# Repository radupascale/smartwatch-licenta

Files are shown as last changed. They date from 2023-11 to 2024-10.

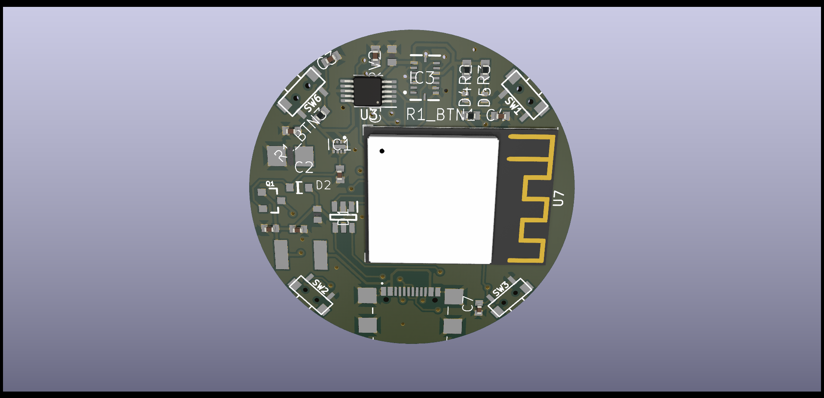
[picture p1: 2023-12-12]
board/proto/docs/route_v1/3d_front.png

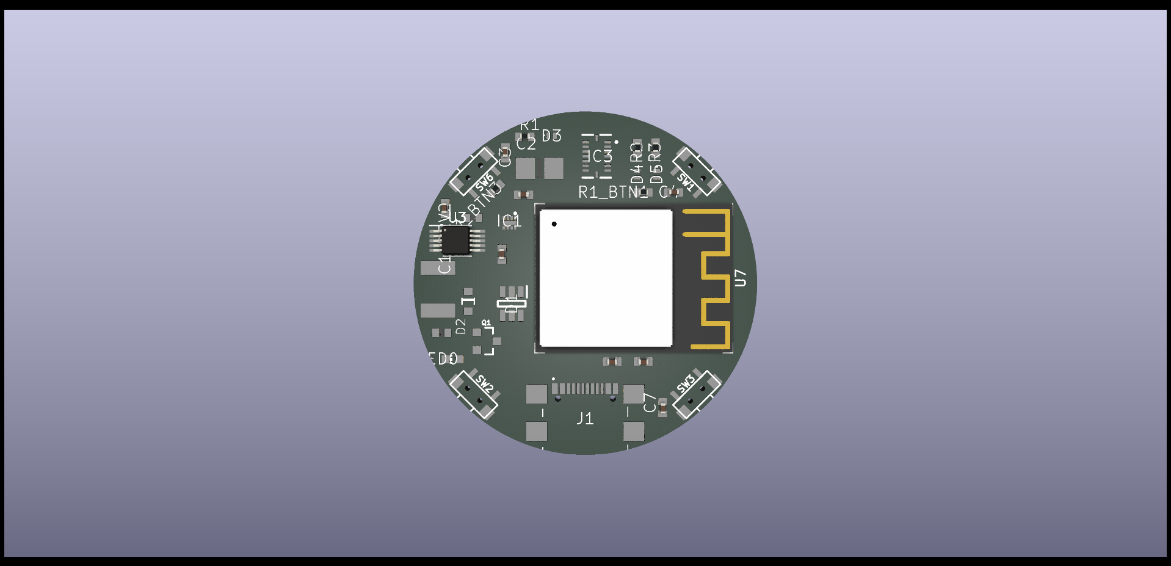
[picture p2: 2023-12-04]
board/proto/docs/proto_v1/3d_front.png

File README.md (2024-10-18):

# Intro

<p align="center">

</p>

This repository contains all the files necessary to build the smartwatch I developed for my thesis at the Computer Science Faculty of UPB.
I plan to add step-by-step building instructions in the future, but for now I'll leave only an overview of the directory structure.

- board: Schematics and PCB layout
    - fusion: Fusion project archive
    - proto: KiCad prototype project
- CAD
    - 3d-files: .stl files for 3D printing the case
    - components: .STEP files for some components
- src: platform.io project files and deps

# Building

```bash
git clone --recurse-submodules git@github.com:radupascale/smartwatch-licenta.git
```

Afterwards open the `src` directory and build&upload using `platformio` (this project used the VScode extension).

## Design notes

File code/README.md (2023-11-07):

## Referinte
- [Hookup display esp32](https://dronebotworkshop.com/gc9a01/)
- [Test display code](https://community.platformio.org/t/tft-display-works-in-arduino-ide-doesnt-in-platformio/33269/5)

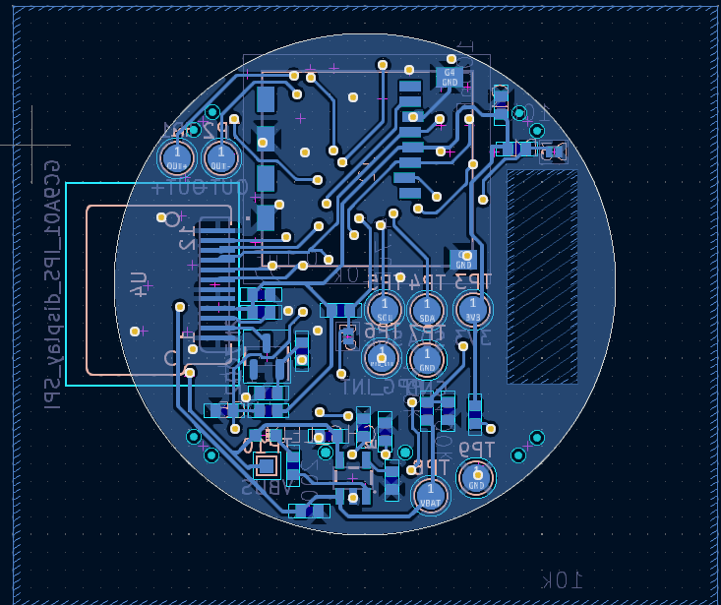
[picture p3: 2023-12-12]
board/proto/docs/route_v1/back.png

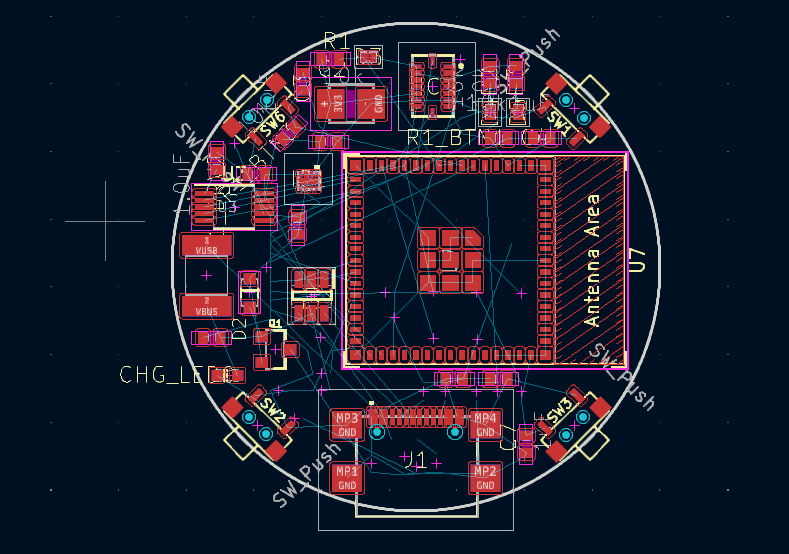
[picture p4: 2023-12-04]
board/proto/docs/proto_v1/front_pcb.png

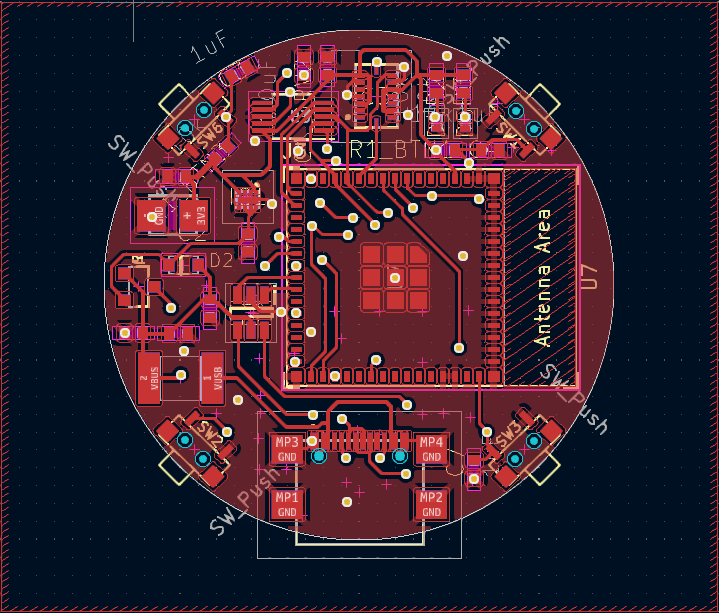
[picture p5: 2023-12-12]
board/proto/docs/route_v1/front.png

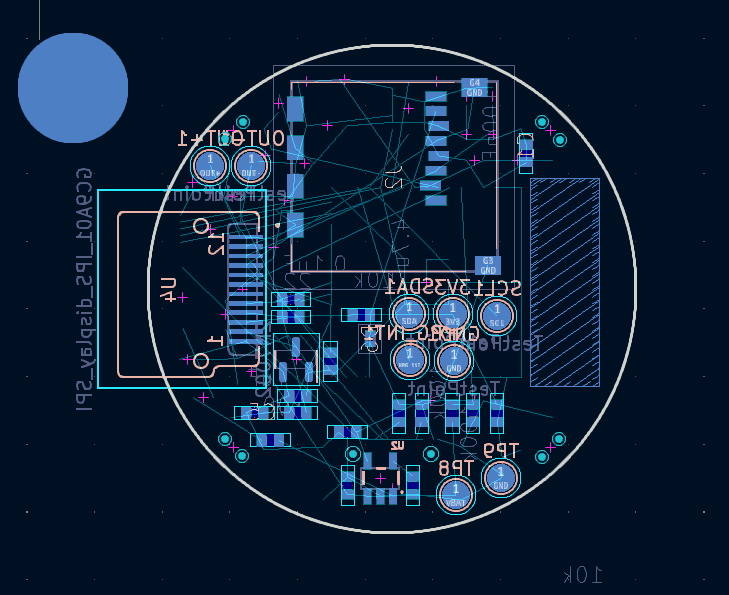
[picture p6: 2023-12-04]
board/proto/docs/proto_v1/back_pcb.png

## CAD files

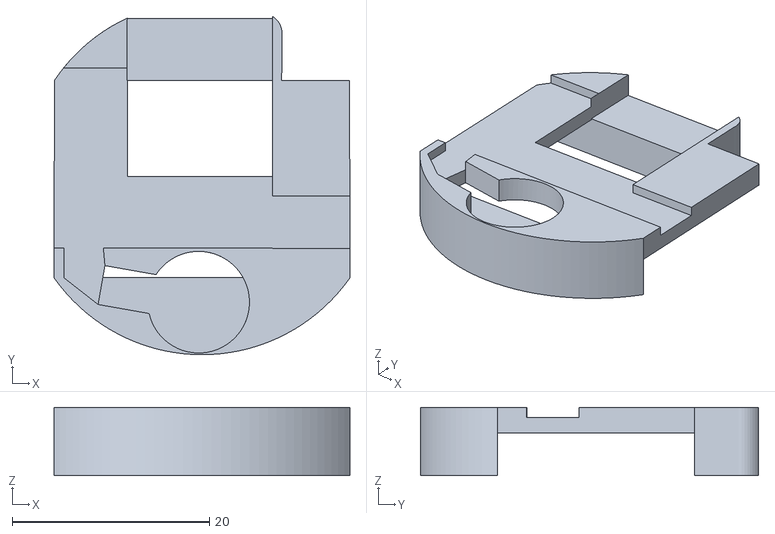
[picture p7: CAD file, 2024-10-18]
CAD/3d-files/battery_holder.stl
30.0 x 34.3 x 6.90

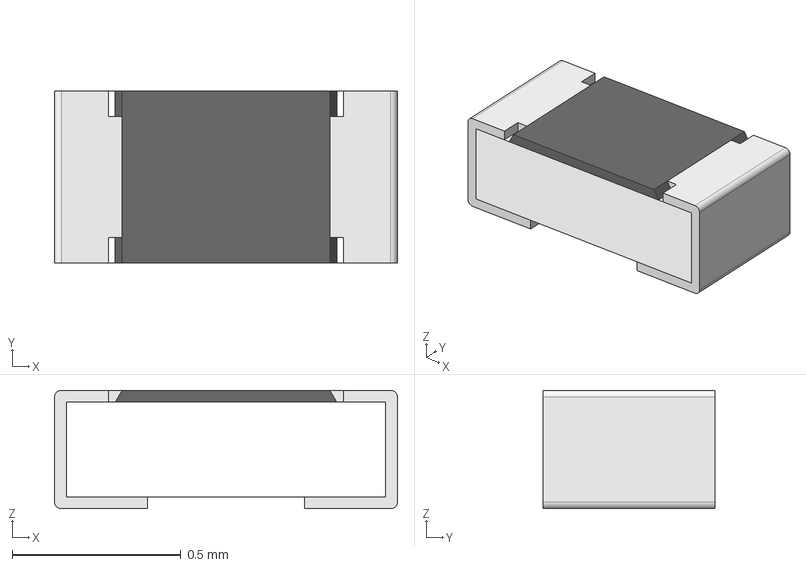
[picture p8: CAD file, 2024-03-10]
CAD/components/Resistor_0402.step
1.02 x 0.508 x 0.35 mm
Pin1
Pin2
CeramicBody
Coating

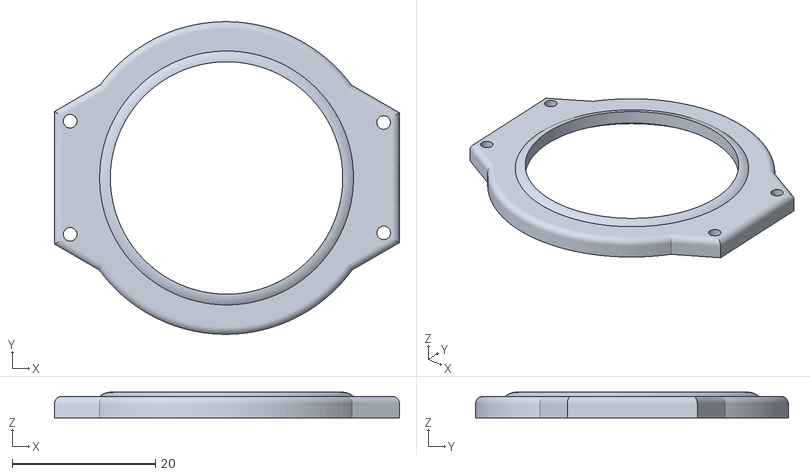
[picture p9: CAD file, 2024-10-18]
CAD/3d-files/top_layer.stl
48.1 x 43.6 x 3.60

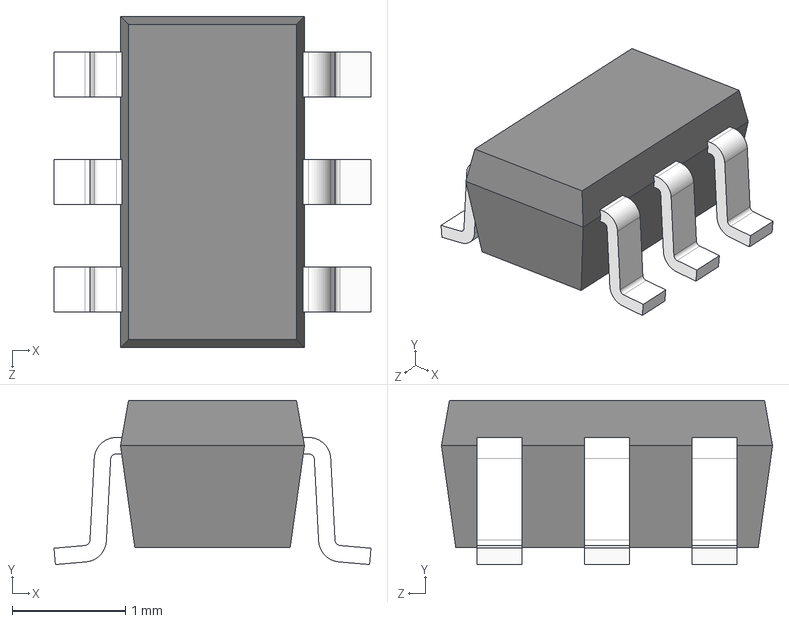
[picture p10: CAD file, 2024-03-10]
CAD/components/USBLC6-2SC6Y--3DModel-STEP-56544.STEP
2.80 x 1.45 x 2.92 mm

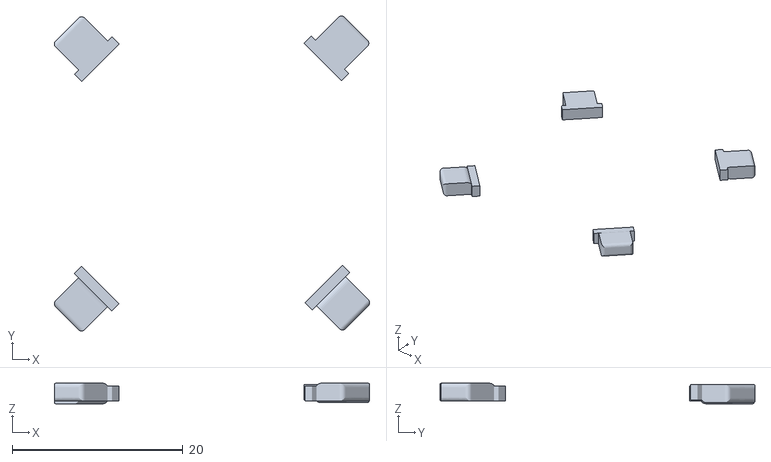
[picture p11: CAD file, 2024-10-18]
CAD/3d-files/buttons.stl
36.9 x 36.8 x 2.40

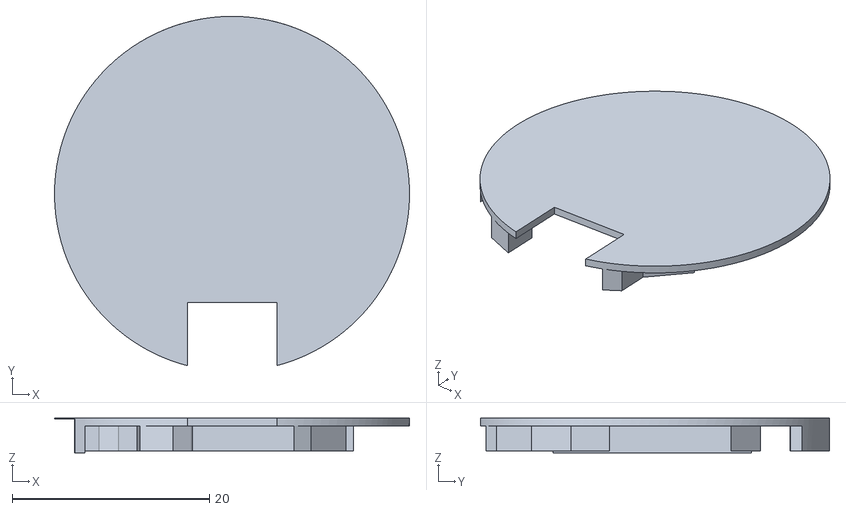
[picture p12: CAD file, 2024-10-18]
CAD/3d-files/interposer.stl
36.0 x 35.4 x 3.50

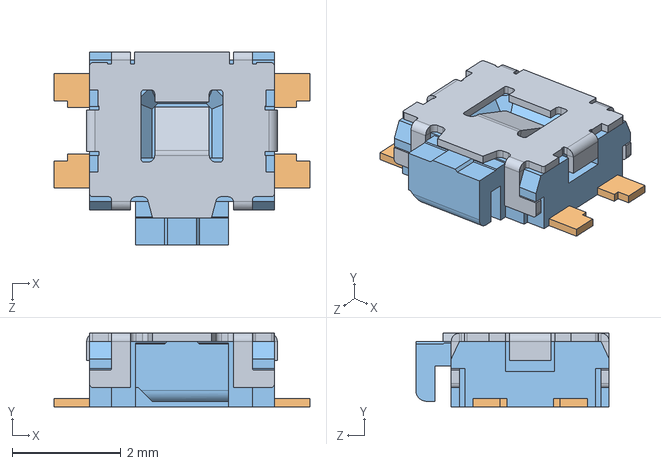
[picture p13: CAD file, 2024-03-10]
CAD/components/EVQ-P7A01P--3DModel-STEP-269445.STEP
4.70 x 1.35 x 3.55 mm

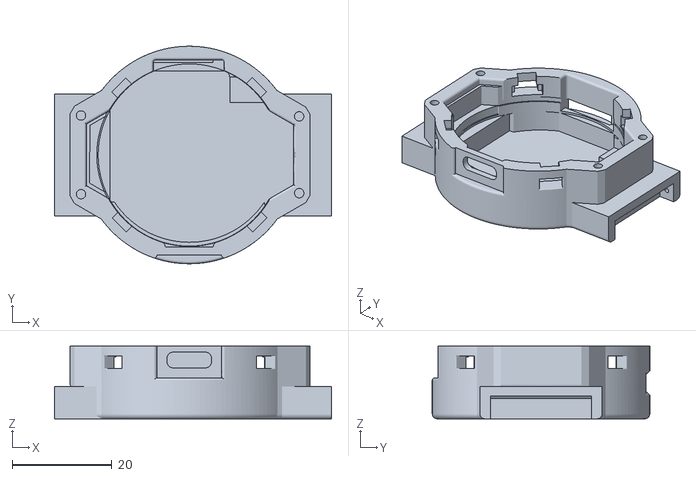
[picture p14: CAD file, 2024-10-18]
CAD/3d-files/bottom_layer.stl
55.5 x 43.6 x 14.5

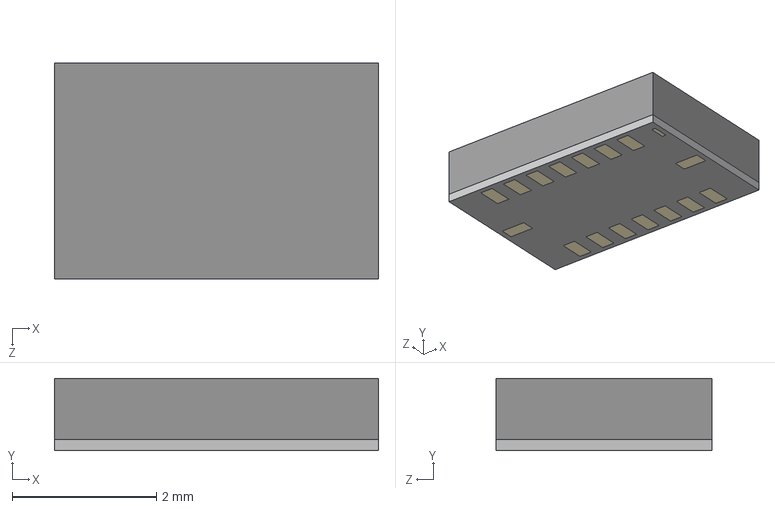
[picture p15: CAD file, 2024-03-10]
CAD/components/BMI085--3DModel-STEP-56544.STEP
4.50 x 1.00 x 3.00 mm

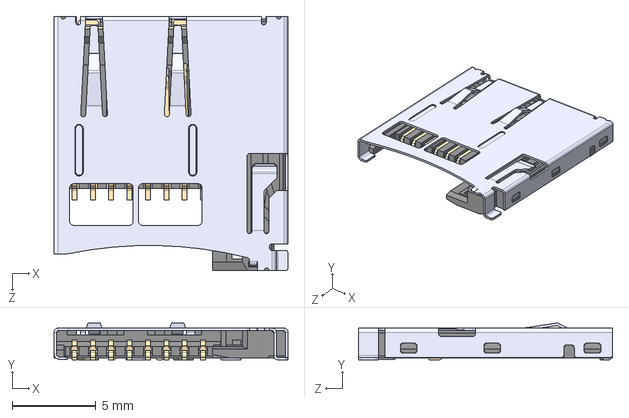
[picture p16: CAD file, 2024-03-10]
CAD/components/112A-TAAR-R03--3DModel-STEP-56544.STEP
14.0 x 2.20 x 15.2 mm

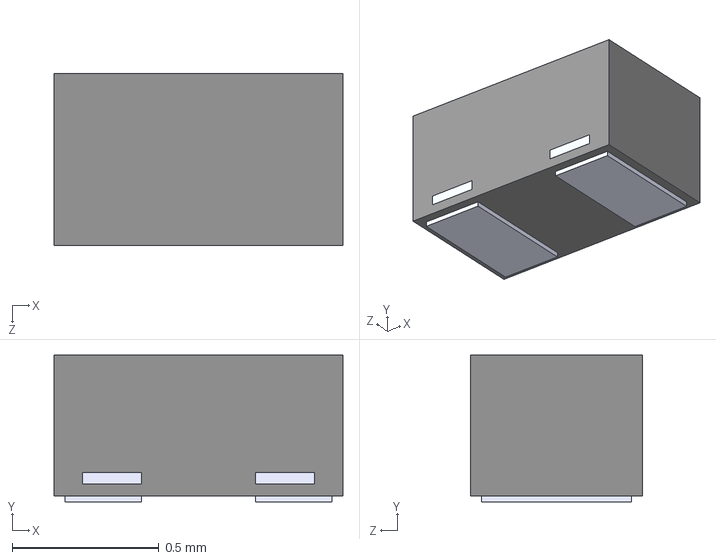
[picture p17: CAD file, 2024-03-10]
CAD/components/PESD5V0S1BL,315.STEP
0.985 x 0.5 x 0.585 mm

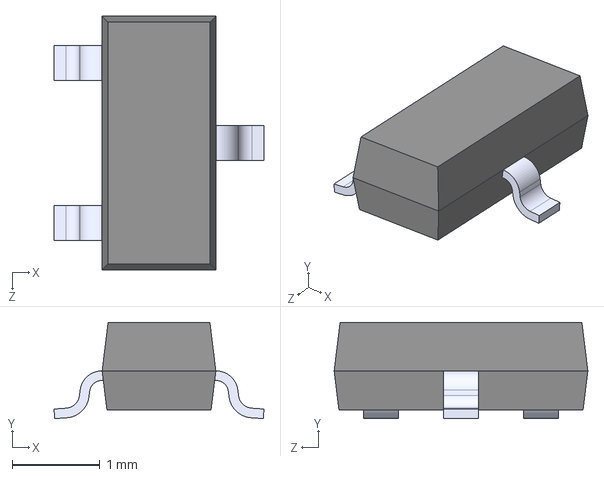
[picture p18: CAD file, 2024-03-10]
CAD/components/DMG2305UX-7.STEP
2.40 x 1.10 x 2.90 mm

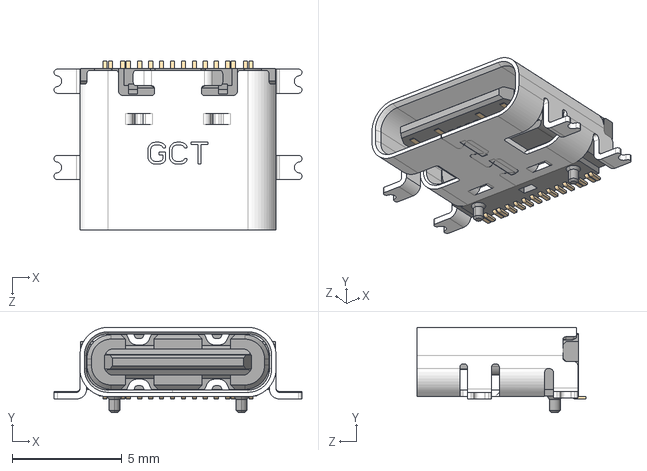
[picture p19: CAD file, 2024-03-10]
CAD/components/USB4110GFA--3DModel-STEP-269445.STEP
11.3 x 3.89 x 7.70 mm

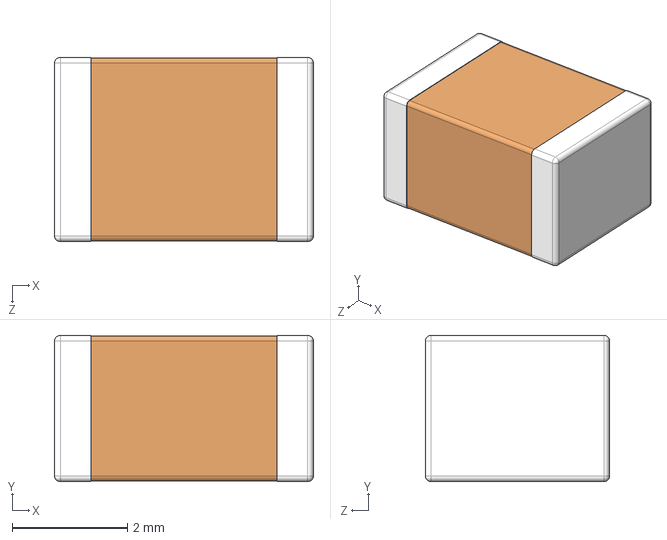
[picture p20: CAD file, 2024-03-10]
CAD/components/VC181238U770DP.STEP
4.50 x 2.54 x 3.20 mm

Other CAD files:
CAD/components/MCP73831T-2ACI_OT.STEP

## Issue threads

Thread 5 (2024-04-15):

Use LVGL with Adafruit GFX

radupascale, 2024-04-15:
The plan is to use Arduino GFX as the backend and LVGL as the frontend because in with it you can preview your work [1] without having to actually upload it to the board.

- [x] update&display test loop

Also, for synchronizing between different tasks which use the LVGL API, use this as a reference [2].

[1] [Simulator](https://docs.lvgl.io/8.1/get-started/pc-simulator.html)
[2] [How to integrate with FreeRTOS](https://github.com/lvgl/lvgl/issues/347#issuecomment-410502996)

Closed 2024-04-23.

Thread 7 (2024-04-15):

3D Case working prototype

radupascale, 2024-04-15:
Redo the 3D case in order to have something in which you can carry the PCB with all other peripherals. Don't over engineer the buttons, just make them click and move.

radupascale, 2024-04-26:
Some more adjustments:

- the buttons should have a hole carved inside of the PCB because right now it's difficult to assemble the case. I should also make them T shaped.
- snap fit between the mid and the bottom layer
- the PCB shouldn't move once you slide it in
- the display should stay level and not lift the PCB with it because this causes some buttons to me misaligned (although this should be fixed with the next PCB iteration). One quick fix would be to lift the button holes 0.1mm
- Top part should snap fit on the display as well as on the mid layer so that it keeps everything into place
- finesse USB port

radupascale, 2024-04-29:
commit a848d6ad20e196f3375dfab03bc0c9b65c634bd9 adds .step files for 3d printing

Closed 2024-04-29.

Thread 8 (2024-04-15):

Test each module

radupascale, 2024-04-15:
I only have these 2 things to test and I'm pretty confident that they will work. However, I need to first make the 3D case #[1].

- [x] PPG
- [x] Haptic motors

[1] https://github.com/radupascale/licenta/issues/7

Closed 2024-04-19.

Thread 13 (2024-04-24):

software core

radupascale, 2024-04-24:
- [x] [main watchface](https://github.com/radupascale/smartwatch-licenta/issues/12)
   - [x] real time
   - [x] app navigation (with another dummy app)
- [x] button event handling
- [x] reading sensor data
  - [x] battery level
  - [x] pedometer #17
- [x] persistent data
  - [x] steps in flash
  - [x] clock time in flash (in case wifi doesn't work)
 - [x] wifi connect option #16

radupascale, 2024-06-24:
8e7f657

Closed 2024-06-24.

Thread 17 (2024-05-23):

Pedometer implementation

radupascale, 2024-05-23:
- [x] pedometer class for reading and interpreting sensor data
- [x] test step count
- [x] step count logging on board and kept across reboots

radupascale, 2024-06-03:
It kind of works (although there are lots of false positives if you move your hand very fast). I'm closing this issue and opening another with for optimizing the algorithm (when I'll have more time).

Closed 2024-06-03.

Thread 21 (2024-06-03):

Repair DRV and motor

radupascale, 2024-06-03:

radupascale, 2024-06-05:
EN pin was not set when sending I2C commands. Apparently setting it to LOW makes the module go in a _low power state_ [1] in which it responds to I2C messages, but writing to registers is undefined behaviour.

[1] https://www.ti.com/lit/ds/symlink/drv2605.pdf

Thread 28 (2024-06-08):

Find battery discharge curve using the internal ADC

radupascale, 2024-06-08:

radupascale, 2024-06-11:
This b102c31 and the previous commit replace the lookup function and provide a script for computing it using adc data

Closed 2024-06-11.

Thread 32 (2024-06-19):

Poll sensors using ULP

radupascale, 2024-06-19:
Read about this [1], maybe it's useful for polling the IMU while the microcontroller is in sleep mode.

[1] https://docs.espressif.com/projects/esp-idf/en/stable/esp32/api-reference/system/ulp.html

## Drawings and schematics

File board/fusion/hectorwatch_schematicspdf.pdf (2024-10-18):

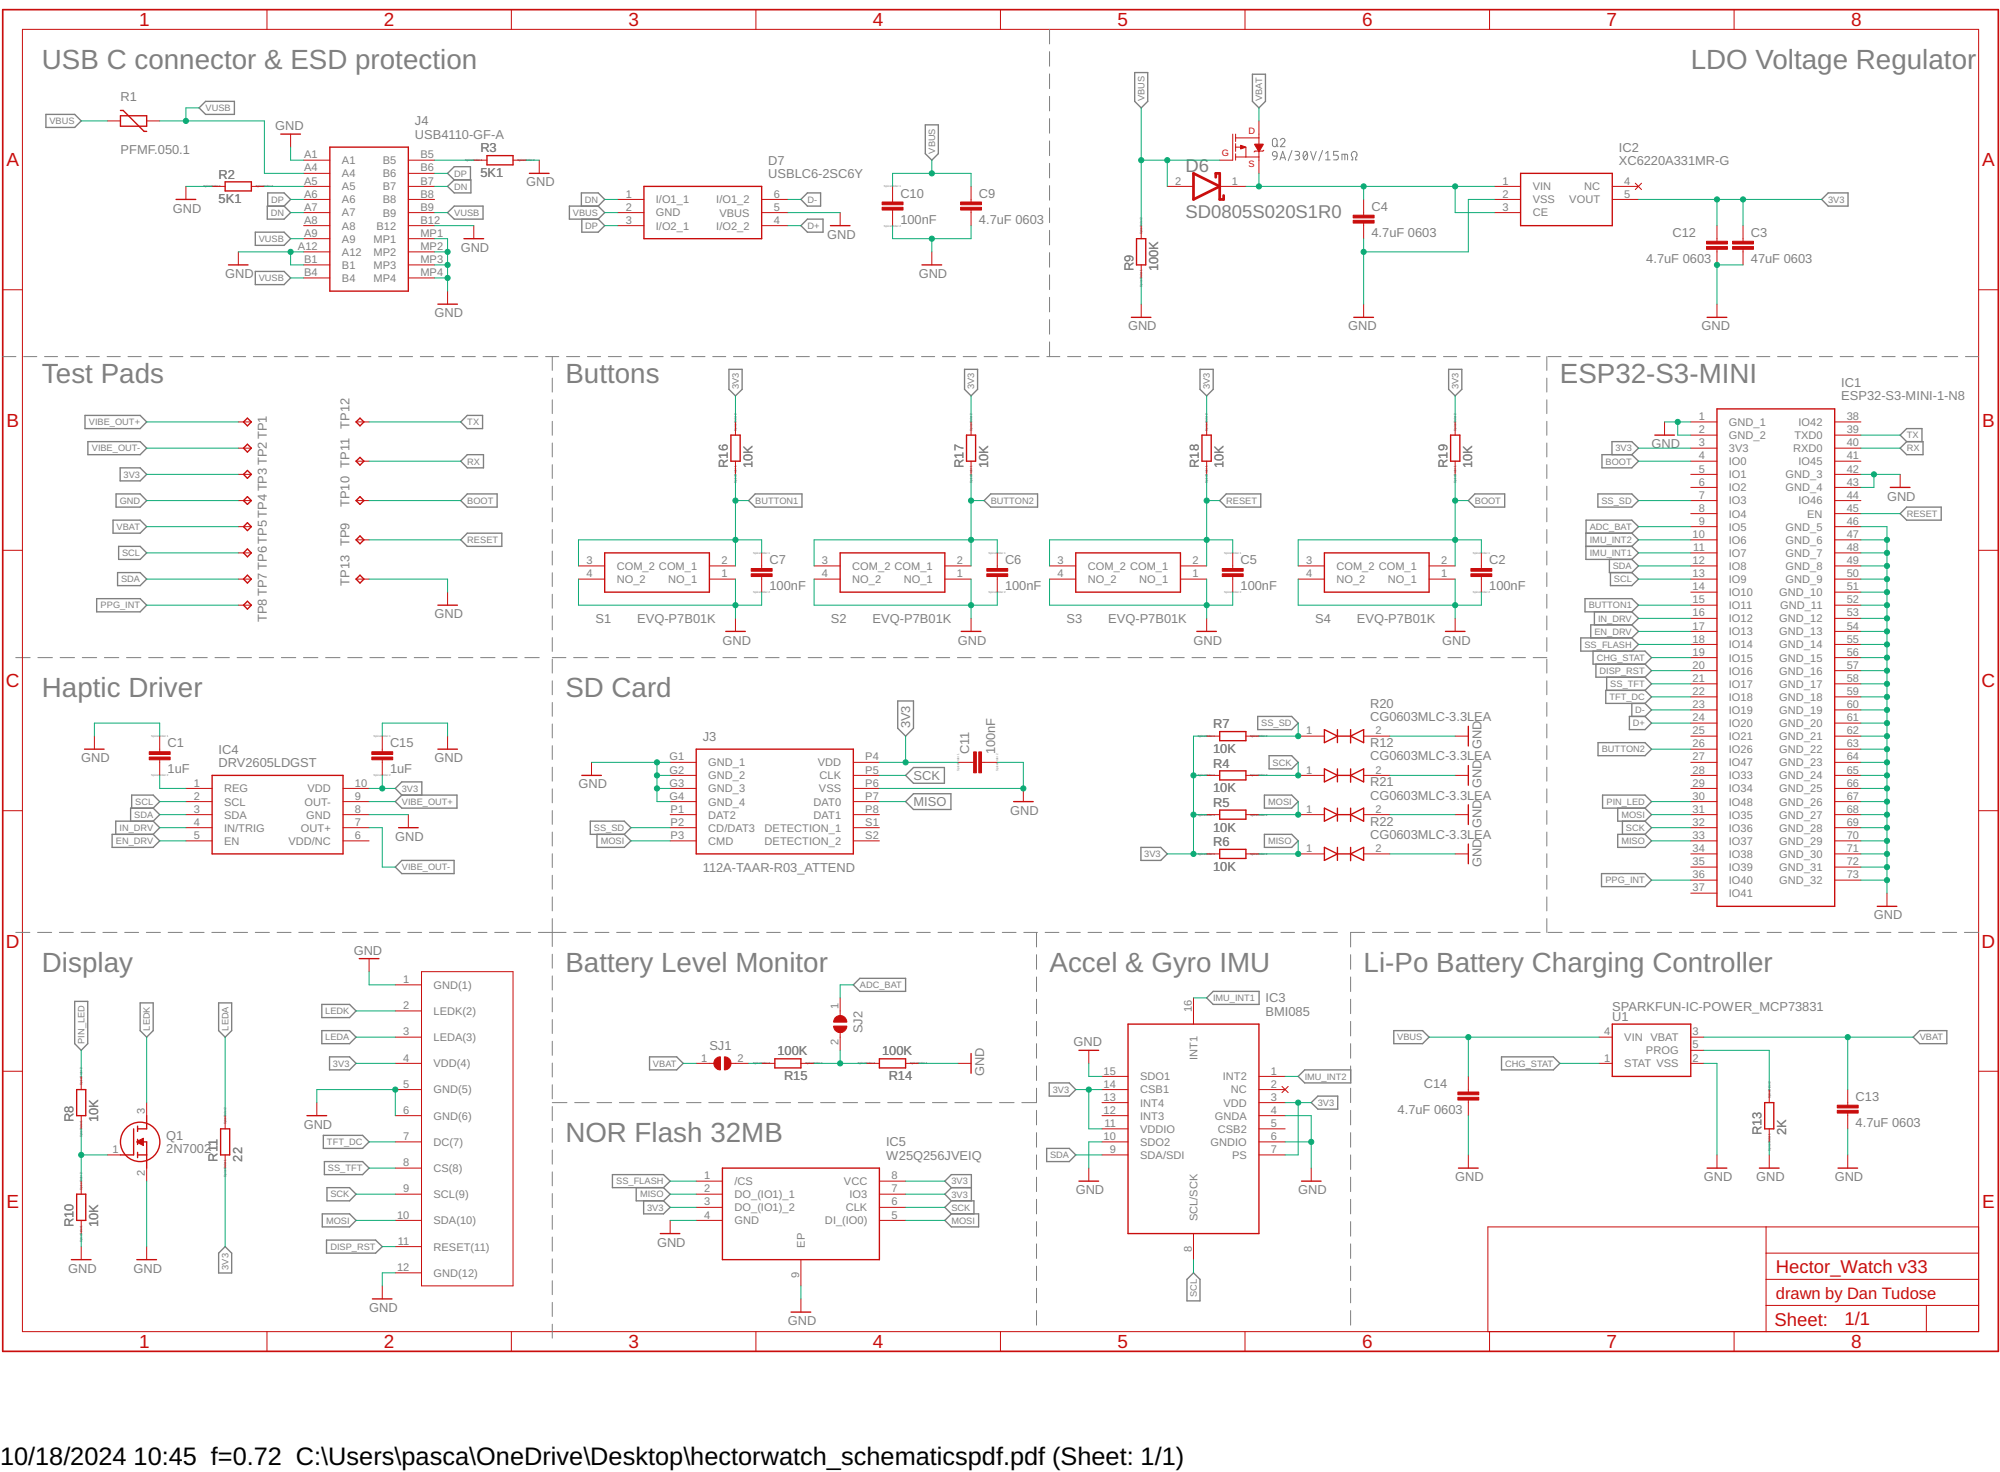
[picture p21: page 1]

USB C connector & ESD protection

SpiceOrder 1 SpiceOrder 2

GND GND

SpiceOrder 1 SpiceOrder 2 SpiceOrder 1 SpiceOrder 2 SpiceOrder 1

10 IMU_INT2 | 47 GND_7

SpiceOrder 1 SpiceOrder 2 SpiceOrder 1 SpiceOrder 2

5 GNDA 4 GNDIO 6

3V3 4 | SCK

drawn by Dan Tudose Hector_Watch v33

10/18/2024 10:45 f=0.72 C:\Users\pasca\OneDrive\Desktop\hectorwatch_schematicspdf.pdf (Sheet: 1/1)

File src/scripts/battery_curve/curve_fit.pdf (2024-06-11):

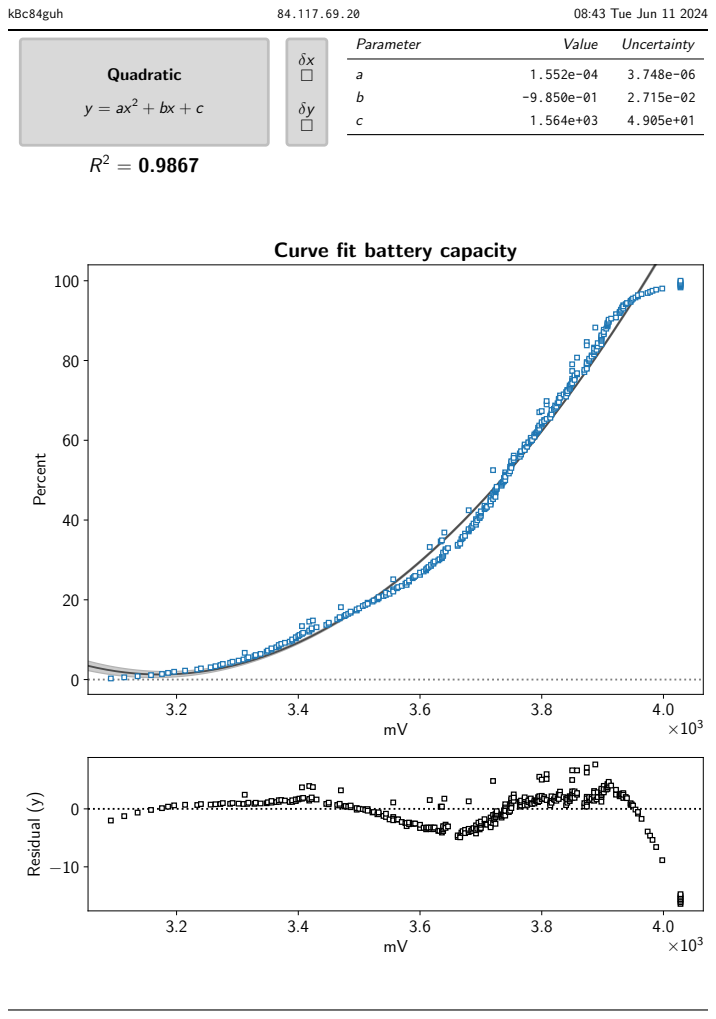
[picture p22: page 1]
kBc84guh; 08:43 Tue Jun 11 2024; Quadratic; Parameter; Value; Uncertainty; Percent; Residual (y)

Curve fit battery capacity

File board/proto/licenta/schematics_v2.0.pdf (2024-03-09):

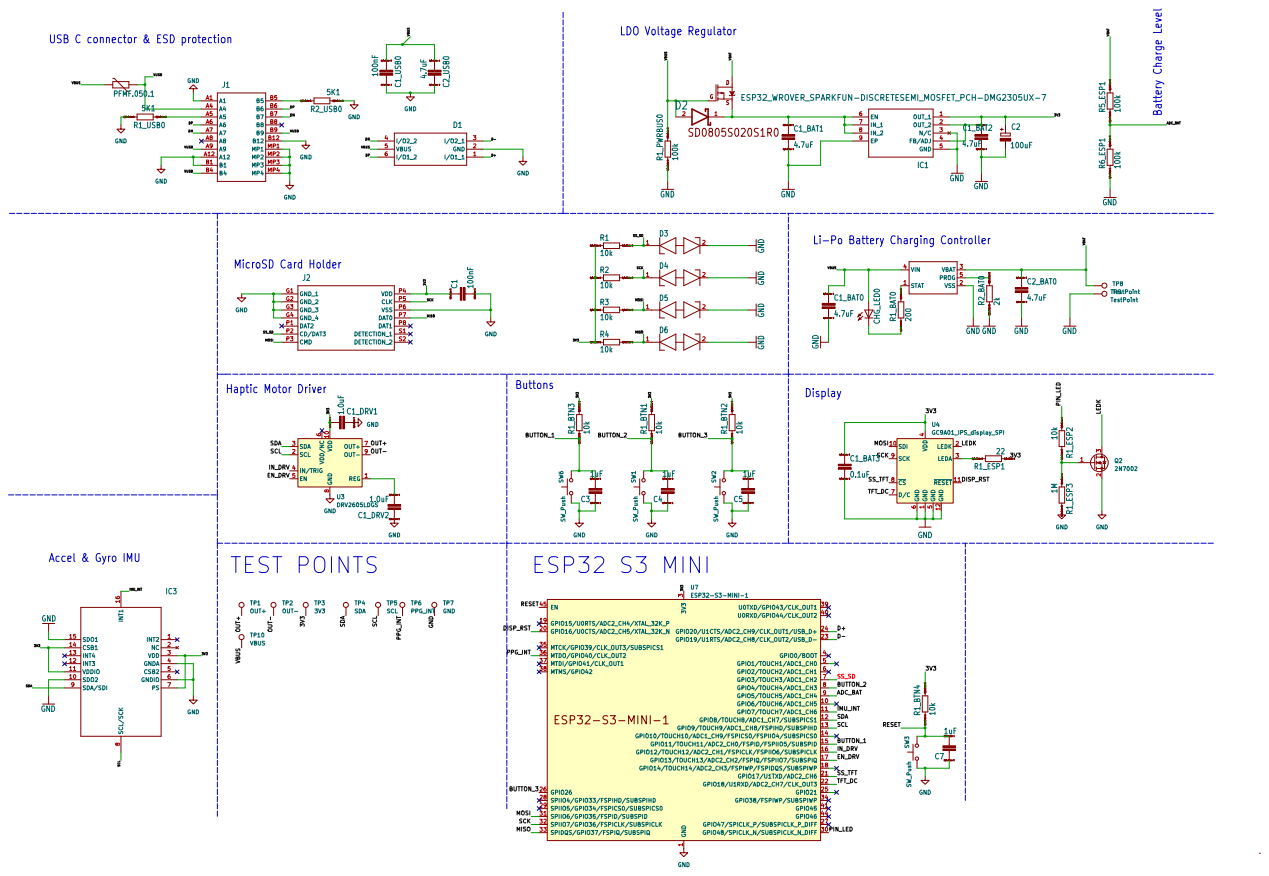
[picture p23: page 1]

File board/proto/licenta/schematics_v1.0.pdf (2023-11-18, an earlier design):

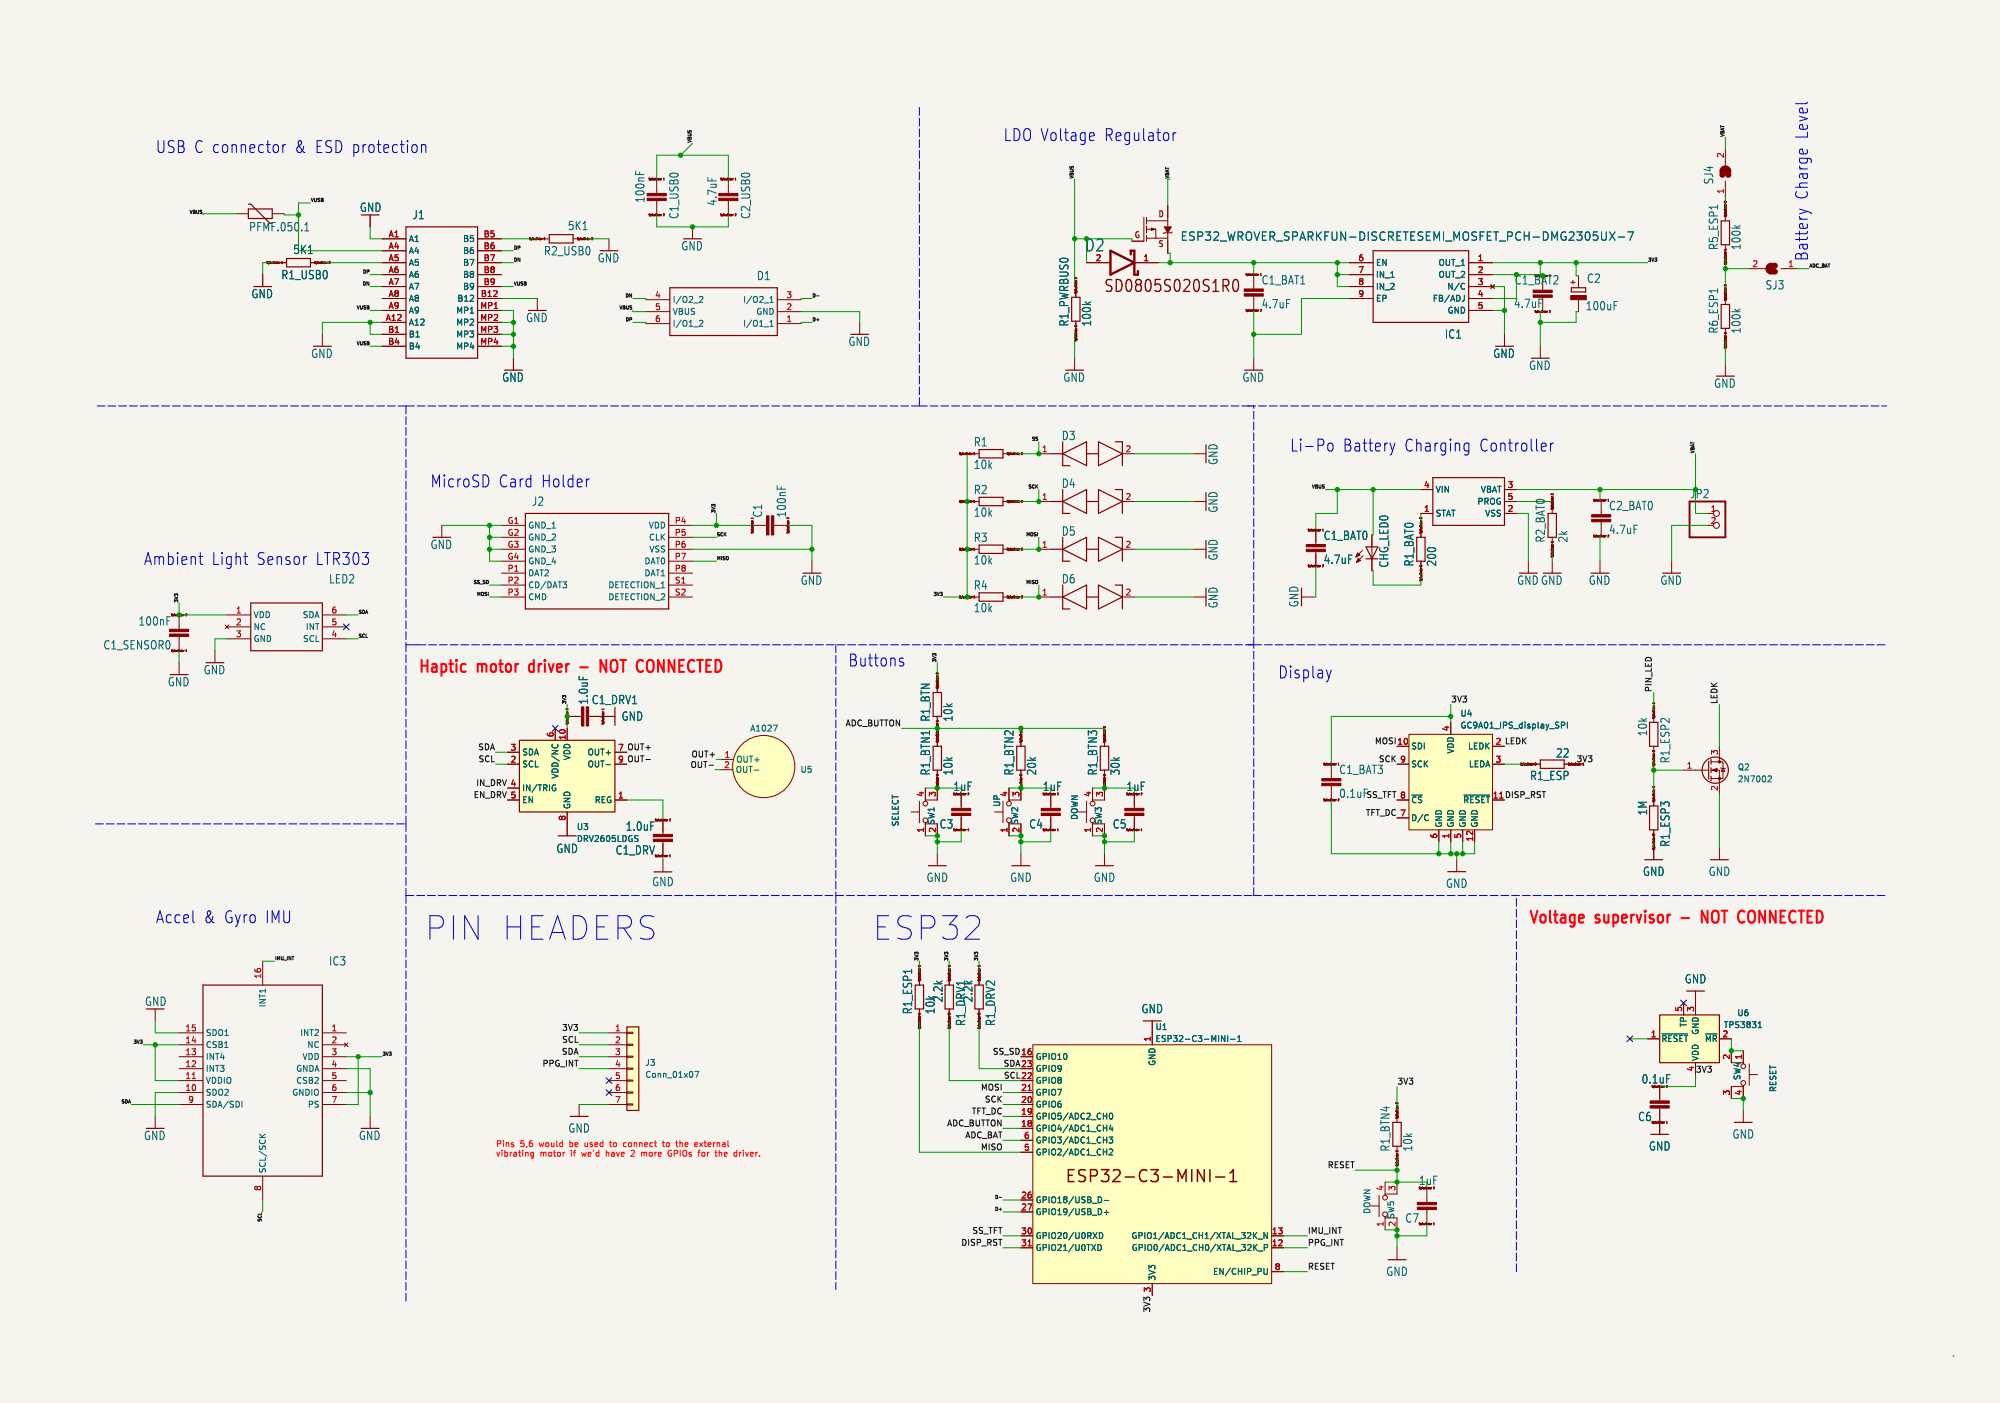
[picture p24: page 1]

Voltage supervisor - NOT CONNECTED Battery Charge Level U4 GC9A01_IPS_display_SPI GND

USB C connector & ESD protection

Li-Po Battery Charging Controller

REG 1 VDD 10 SCL 2 SDA 3

U3 DRV2605LDGS REG 1 VDD 10 SCL 2 SDA 3

3 SW2UP SpiceOrder 1 SpiceOrder 2 R1_DRV2 2.2k SpiceOrder 1 SpiceOrder 2 R1_ESP1 10k SpiceOrder 1 SpiceOrder 2 R1_DRV1 2.2k

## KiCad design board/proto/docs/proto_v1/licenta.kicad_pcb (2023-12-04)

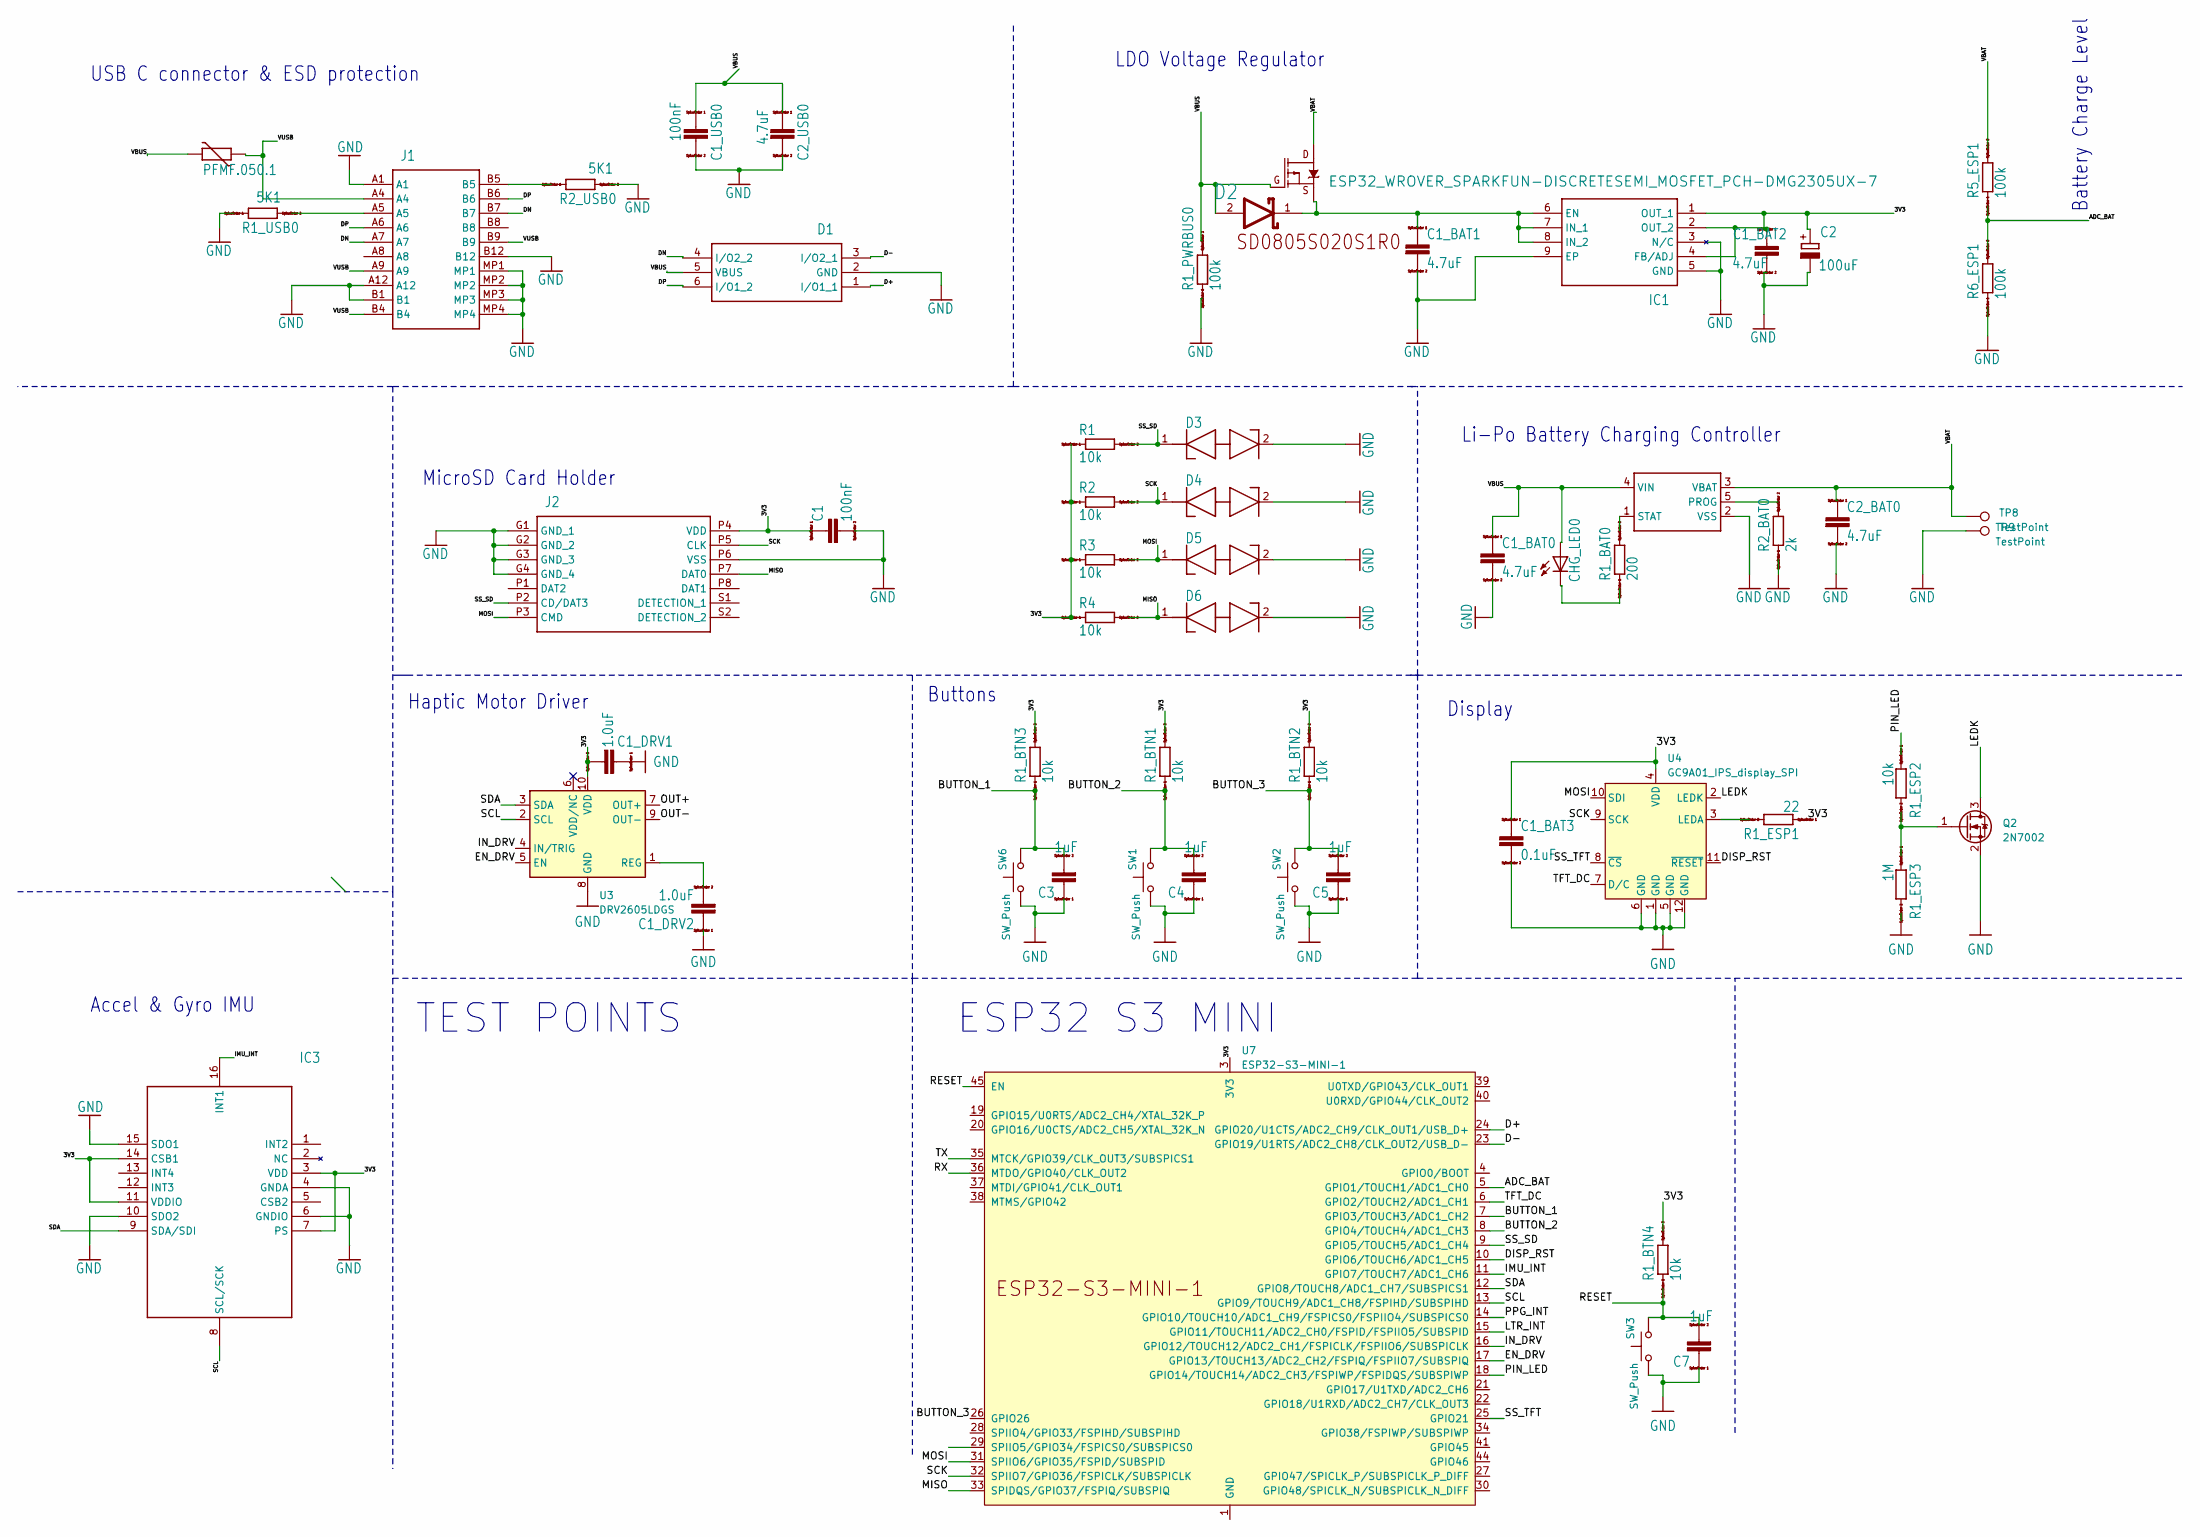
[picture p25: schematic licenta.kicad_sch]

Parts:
C1, C1_USB0: 100nF; ESP32_WROVER_EAGLE-LTSPICE_C0402
C1_BAT0, C1_BAT1, C1_BAT2, C2_BAT0, C2_USB0: 4.7uF; ESP32_WROVER_EAGLE-LTSPICE_C0402
C1_BAT3: 0.1uF; ESP32_WROVER_EAGLE-LTSPICE_C0402
C1_DRV1, C1_DRV2: 1.0uF; ESP32_WROVER_EAGLE-LTSPICE_C0402
C2: 100uF; RCL_CT3528
C3, C4, C5, C7: 1uF; ESP32_WROVER_EAGLE-LTSPICE_C0402
CHG_LED0: ESP32_WROVER_ADAFRUIT_LEDCHIP-LED0603; ESP32_WROVER_ADAFRUIT_CHIP-LED0603
D1: SAMACSYS_PARTS_USBLC6-2SC6Y; SAMACSYS_PARTS_SOT95P280X145-6N
D2: ESP32_WROVER_AVX---SD0805S020S1R0_AVX_SD0805S020S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; ESP32_WROVER_AVX---SD0805S020S1R0_AVX_SD0805S020S1R0_0
D3, D4, D5, D6: SAMACSYS_PARTS_PESD3V3S1BLYL; SAMACSYS_PARTS_PESD5V0S1BL315
IC1: SAMACSYS_PARTS_NCP186BMX330TAG; SAMACSYS_PARTS_NCP186AMX330TAG
IC3: SAMACSYS_PARTS_BMI085
J1: SAMACSYS_PARTS_USB4110-GF-A; SAMACSYS_PARTS_USB4110GFA
J2: SAMACSYS_PARTS_112A-TAAR-R03_ATTEND; SAMACSYS_PARTS_112ATAARR03ATTEND
PFMF.050.1: ESP32_WROVER_VARISTOR_VARISTORCN1812; ESP32_WROVER_VARISTOR_CT_CN1812
Q1: ESP32_WROVER_SPARKFUN-DISCRETESEMI_MOSFET_PCH-DMG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; ESP32_WROVER_SPARKFUN-DISCRETESEMI_SOT23-3
Q2: 2N7002; SOT-23
R1, R1_BTN1, R1_BTN2, R1_BTN3, R1_BTN4, R1_ESP2, R2, R3, R4: 10k; ESP32_WROVER_EAGLE-LTSPICE_R0402
R1_BAT0: 200; ESP32_WROVER_EAGLE-LTSPICE_R0402
R1_ESP1: 22; ESP32_WROVER_EAGLE-LTSPICE_R0402
R1_ESP3: 1M; ESP32_WROVER_EAGLE-LTSPICE_R0402
R1_PWRBUS0, R5_ESP1, R6_ESP1: 100k; ESP32_WROVER_EAGLE-LTSPICE_R0402
R1_USB0, R2_USB0: 5K1; ESP32_WROVER_EAGLE-LTSPICE_R0402
R2_BAT0: 2k; ESP32_WROVER_EAGLE-LTSPICE_R0402
SW1, SW2, SW3, SW6: SW_Push; button_side_smd
TP8, TP9: TestPoint; TestPoint_Pad_D2.0mm
U2: ESP32_WROVER_SPARKFUN-IC-POWER_MCP73831; ESP32_WROVER_SPARKFUN-IC-POWER_SOT23-5
U3: DRV2605LDGS; VSSOP-10_3x3mm_P0.5mm
U4: GC9A01_IPS_display_SPI; GC9A01_IPS_display
U7: ESP32-S3-MINI-1

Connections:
/3V3: C1.1, C1_BAT2.1, C1_BAT3.1, C1_DRV1.2, C2.+, IC1.1 (OUT_1), IC1.2 (OUT_2), IC1.4 (FB/ADJ), IC3.3 (VDD), IC3.7 (PS), IC3.11 (VDDIO), IC3.14 (CSB1), J2.P4 (VDD), R1.1, R1_BTN1.2, R1_BTN2.2, R1_BTN3.2, R1_BTN4.2, R1_ESP1.1, R2.1, R3.1, R4.1, U3.10 (VDD), U4.4 (VDD), U7.3 (3V3); also elsewhere on the board
/ADC_BAT: R5_ESP1.1, R6_ESP1.2, U7.5 (GPIO1/TOUCH1/ADC1_CH0)
/BUTTON_1: C3.2, R1_BTN3.1, SW6.2, U7.7 (GPIO3/TOUCH3/ADC1_CH2)
/BUTTON_2: C4.2, R1_BTN1.1, SW1.2, U7.8 (GPIO4/TOUCH4/ADC1_CH3)
/BUTTON_3: C5.2, R1_BTN2.1, SW2.2, U7.26 (GPIO26)
/D+: D1.1 (I/O1_1), U7.24 (GPIO20/U1CTS/ADC2_CH9/CLK_OUT1/USB_D+)
/D-: D1.3 (I/O2_1), U7.23 (GPIO19/U1RTS/ADC2_CH8/CLK_OUT2/USB_D-)
/DISP_RST: U4.11 (~RESET), U7.10 (GPIO6/TOUCH6/ADC1_CH5)
/DN: D1.4 (I/O2_2), J1.A7, J1.B7
/DP: D1.6 (I/O1_2), J1.A6, J1.B6
/EN_DRV: U3.5 (EN), U7.17 (GPIO13/TOUCH13/ADC2_CH2/FSPIQ/FSPIIO7/S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)
/IMU_INT: IC3.16 (INT1), U7.11 (GPIO7/TOUCH7/ADC1_CH6)
/IN_DRV: U3.4 (IN/TRIG), U7.16 (GPIO12/TOUCH12/ADC2_CH1/FSPICLK/FSPIIO6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)
/LEDK: Q2.3 (D), U4.2 (LEDK)
/LTR_INT: U7.15 (GPIO11/TOUCH11/ADC2_CH0/FSPID/FSPIIO5/S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)
/MISO: D6.1 (K1), J2.P7 (DAT0), R4.2, U7.33 (SPIDQS/GPIO37/FSPIQ/SUBSPIQ)
/MOSI: D5.1 (K1), J2.P3 (CMD), R3.2, U4.10 (SDI), U7.31 (SPIIO6/GPIO35/FSPID/SUBSPID)
/OUT+: U3.7 (OUT+); also elsewhere on the board
/OUT-: U3.9 (OUT-); also elsewhere on the board
/PIN_LED: R1_ESP2.1, U7.18 (GPIO14/TOUCH14/ADC2_CH3/FSPIWP/FSPIDQS/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)
/PPG_INT: U7.14 (GPIO10/TOUCH10/ADC1_CH9/FSPICS0/FSPIIO4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); also elsewhere on the board
/RESET: C7.2, R1_BTN4.1, SW3.2, U7.45 (EN)
/RX: U7.36 (MTDO/GPIO40/CLK_OUT2)
/SCK: D4.1 (K1), J2.P5 (CLK), R2.2, U4.9 (SCK), U7.32 (SPIIO7/GPIO36/FSPICLK/SUBSPICLK)
/SCL: IC3.8 (SCL/SCK), U3.2 (SCL), U7.13 (GPIO9/TOUCH9/ADC1_CH8/FSPIHD/SUBSPIHD); also elsewhere on the board
/SDA: IC3.9 (SDA/SDI), U3.3 (SDA), U7.12 (GPIO8/TOUCH8/ADC1_CH7/SUBSPICS1); also elsewhere on the board
/SS_SD: D3.1 (K1), J2.P2 (CD/DAT3), R1.2, U7.9 (GPIO5/TOUCH5/ADC1_CH4)
/SS_TFT: U4.8 (~CS), U7.25 (GPIO21)
/TFT_DC: U4.7 (D/C), U7.6 (GPIO2/TOUCH2/ADC1_CH1)
/TX: U7.35 (MTCK/GPIO39/CLK_OUT3/SUBSPICS1)
/VBAT: C2_BAT0.1, Q1.3 (D), R5_ESP1.2, TP8.1, U2.3 (VBAT)
/VBUS: C1_BAT0.1, C1_USB0.1, C2_USB0.1, CHG_LED0.A, D1.5 (VBUS), D2.2 (ANODE), PFMF.050.1.2, Q1.1 (G), R1_PWRBUS0.2, U2.4 (VIN)
/VUSB: J1.A4, J1.A9, J1.B4, J1.B9, PFMF.050.1.1
GND: C1.2, C1_BAT0.2, C1_BAT1.2, C1_BAT2.2, C1_BAT3.2, C1_DRV1.1, C1_DRV2.1, C1_USB0.2, C2.-, C2_BAT0.2, C2_USB0.2, C3.1, C4.1, C5.1, C7.1, D1.2 (GND), D3.2 (K2), D4.2 (K2), D5.2 (K2), D6.2 (K2), IC1.3 (N/C), IC1.5 (GND), IC1.9 (EP), IC3.4 (GNDA), IC3.6 (GNDIO), IC3.10 (SDO2), IC3.15 (SDO1), J1.A1, J1.A12, J1.B1, J1.B12, J1.MP1, J1.MP2, J1.MP3, J1.MP4, J2.G1 (GND_1), J2.G2 (GND_2), J2.G3 (GND_3), J2.G4 (GND_4), J2.P6 (VSS), Q2.2 (S), R1_ESP3.2, R1_PWRBUS0.1, R1_USB0.1, R2_BAT0.1, R2_USB0.2, R6_ESP1.1, SW1.1, SW2.1, SW3.1, SW6.1, TP9.1, U2.2 (VSS), U3.8 (GND), U4.1 (GND), U4.5 (GND), U4.6 (GND), U4.12 (GND); also elsewhere on the board
unnamed: CHG_LED0.C, R1_BAT0.1
unnamed: C1_BAT1.1, D2.1 (CATHODE), IC1.6 (EN), IC1.7 (IN_1), IC1.8 (IN_2), Q1.2 (S)
unnamed: J1.A5, R1_USB0.2
unnamed: J1.B5, R2_USB0.1
unnamed: Q2.1 (G), R1_ESP2.2, R1_ESP3.1
unnamed: R2_BAT0.2, U2.5 (PROG)
unnamed: R1_BAT0.2, U2.1 (STAT)
unnamed: C1_DRV2.2, U3.1 (REG)
unnamed: R1_ESP1.2, U4.3 (LEDA)
unnamed: U7.1 (GND), U7.2 (GND), U7.42 (GND), U7.43 (GND), U7.46 (GND), U7.47 (GND), U7.48 (GND), U7.49 (GND), U7.50 (GND), U7.51 (GND), U7.52 (GND), U7.53 (GND), U7.54 (GND), U7.55 (GND), U7.56 (GND), U7.57 (GND), U7.58 (GND), U7.59 (GND), U7.60 (GND), U7.61 (GND), U7.62 (GND), U7.63 (GND), U7.64 (GND), U7.65 (GND)

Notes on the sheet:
TEST POINTS
MicroSD Card Holder
Buttons
USB C connector & ESD protection
Haptic Motor Driver
Li-Po Battery Charging Controller
Accel & Gyro IMU
ESP32 S3 MINI
Display
Battery Charge Level
LDO Voltage Regulator

Board: 2 copper layers, 64 parts (31 on the bottom side), 41 nets, no tracks yet.

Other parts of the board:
3V3: TestPoint; TestPoint_Pad_D2.0mm
GND1: TestPoint; TestPoint_Pad_D2.0mm
OUT+1: TestPoint; TestPoint_Pad_D2.0mm
OUT-1: TestPoint; TestPoint_Pad_D2.0mm
PPG_INT1: TestPoint; TestPoint_Pad_D2.0mm
SCL1: TestPoint; TestPoint_Pad_D2.0mm
SDA1: TestPoint; TestPoint_Pad_D2.0mm

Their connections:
/3V3: 3V3.1; also elsewhere on the board
/OUT+: OUT+1.1; also elsewhere on the board
/OUT-: OUT-1.1; also elsewhere on the board
/PPG_INT: PPG_INT1.1; also elsewhere on the board
/SCL: SCL1.1; also elsewhere on the board
/SDA: SDA1.1; also elsewhere on the board
GND: GND1.1; also elsewhere on the board

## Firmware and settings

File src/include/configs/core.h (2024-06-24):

#pragma once
#include "driver/adc.h"
#include "driver/gpio.h"

#define ADC_BAT ADC1_CHANNEL_4
#define CHG_STAT GPIO_NUM_15
#define BUTTON_SELECT GPIO_NUM_0
#define BUTTON_UP GPIO_NUM_11
#define BUTTON_DOWN GPIO_NUM_26
#define RTC_GPIO0 BUTTON_UP

#define BOARD_MISO 37
#define BOARD_SCK 36
#define BOARD_MOSI 35
#define SS_SD 3
#define SS_TFT 17
#define SS_FLASH GPIO_NUM_14
#define EN_DRV GPIO_NUM_13

#define SPI_SPEED (5000000UL)

#define NVS_PEDOMETER_PART "pedometer"
#define DEFAULT_NAMESPACE "default"

#define TWDT_TIMEOUT_MS 3000
#define DEFAULT_CPU_FREQ_MHZ 40
#define ANTENNA_CPU_FREQ_MHZ 80 // wifi and bluetooth only works at this freq
#define INACTIVE_CPU_FREQ_MHZ 20

/* App and GUI notifications */
#define EVENT_NONE (0x00)
#define EVENT_LONG_SELECT (0x01)
#define EVENT_BACK (0x02)
#define EVENT_UP (0x03)
#define EVENT_DOWN (0x04)
#define EVENT_SELECT (0x05)

void os_init(void *pvParam);
void os_gui(void *pvParam);
void os_resumer(void *pvParam);

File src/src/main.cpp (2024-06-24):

#include "apps/gui.h"
#include "apps/pedometer.h"
#include "apps/settings_app.h"
#include "apps/watchface.h"
#include "components/boardsettings.h"

#include "configs/core.h"
#include "driver/adc.h"
#include "driver/gpio.h"
#include "esp_adc_cal.h"
#include "esp_log.h"
#include "esp_system.h"

#include "esp32/clk.h"
#include "freertos/FreeRTOS.h"
#include "freertos/queue.h"
#include "freertos/semphr.h"
#include "freertos/task.h"
#include <stdio.h>

static char const *MAIN_TAG = "MAIN";

static DeviceManager *deviceManager = nullptr;
static BoardSettings *settings = nullptr;
static WatchFace *watchFace = nullptr;
static Settings *settingsApp = nullptr;
static Pedometer *pedometer = nullptr;

TaskHandle_t gui_task;
TaskHandle_t display_task;
TaskHandle_t resumer_task;
TaskHandle_t button_task;
static SemaphoreHandle_t lvgl_mutex;
static GUI *gui = nullptr;

void os_init()
{
	/* Initialize LVGL mutex */
	lvgl_mutex = xSemaphoreCreateBinary();
	if (lvgl_mutex != NULL) {
		ESP_LOGI(MAIN_TAG, "LVGL Mutex created");
		xSemaphoreGive(lvgl_mutex);
	}

	/* TODO: call it board */
	settings = new BoardSettings();
	settings->init();

	deviceManager = new DeviceManager();
	deviceManager->init(settings);

	/* Initialize applications */
	/* TODO: why do these also get settings as an argument?  */
	pedometer = new Pedometer(deviceManager, "Pedometer");
	watchFace = new WatchFace(deviceManager, "Watchface");
	watchFace->attach_pedometer(pedometer);
	settingsApp = new Settings(deviceManager, "Settings");

	/* TODO: init gui */
	gui = new GUI();
	gui->init(watchFace);
	/* TODO: add applications */
	gui->add_app(settingsApp);

	ESP_LOGI(MAIN_TAG, "Finish modules initialization. Boot count: %d",
			 settings->get_boot_count());
}

void os_update_display(void *pvParameter)
{
	Display *display = deviceManager->get_display();
	uint32_t ulNotifiedValue = 0x00;

	while (1) {
		xTaskNotifyWait(0, 0, &ulNotifiedValue, pdMS_TO_TICKS(200));

		if (ulNotifiedValue & PAUSE_TASK) {
			ESP_LOGI(MAIN_TAG, "Pause Update display");
			display->disable();

			/* Note: the event it is waiting for is RESUME_TASK */
			xTaskNotifyWait(ULONG_MAX, ULONG_MAX, &ulNotifiedValue,
							portMAX_DELAY);
			display->enable();
			ESP_LOGI(MAIN_TAG, "Resume update display");
		}
		/**
		 * LVGL is not thread safe, use this to guard display update
		 * operations, see this: https://docs.lvgl.io/8.3/porting/os.html
		 */
		xSemaphoreTake(lvgl_mutex, portMAX_DELAY);
		gui->get_current_app()->update_ui();
		display->render();
		xSemaphoreGive(lvgl_mutex);
	}
}

void os_gui(void *pvParameter)
{
	uint32_t ulNotifiedValue = 0x00;

	while (1) {
		xTaskNotifyWait(ULONG_MAX, ULONG_MAX, &ulNotifiedValue, portMAX_DELAY);

		// lock mutex
		xSemaphoreTake(lvgl_mutex, portMAX_DELAY);
		gui->handle_event(ulNotifiedValue);
		xSemaphoreGive(lvgl_mutex);
	}
}

void os_pedometer(void *pvParameter)
{
	steps_t step_count;
	steps_t last_step_count = pedometer->get_steps();
	steps_t delta = 10;
	pedometer->reset_algorithm();

	while (1) {
		pedometer->count_steps();

		step_count = pedometer->get_steps();

		if (step_count - last_step_count > delta) {
			last_step_count = step_count;
			pedometer->write_todays_steps();
		}
		vTaskDelay(pdMS_TO_TICKS(20));
	}
}

/**
 * @brief Task which checks button events every 5ms (as mentioned in the
 * ACEButton library README)
 *
 * @param pvParameter
 */
void os_check_buttons(void *pvParameter)
{
	uint32_t ulNotifiedValue;

	while (1) {
		xTaskNotifyWait(0, 0, &ulNotifiedValue, pdMS_TO_TICKS(5));

		if (ulNotifiedValue & PAUSE_TASK) {
			ESP_LOGI(MAIN_TAG, "Pausing button task");
			/* Note: the event it is waiting for is RESUME_TASK */
			xTaskNotifyWait(ULONG_MAX, ULONG_MAX, &ulNotifiedValue,
							portMAX_DELAY);
			ESP_LOGI(MAIN_TAG, "Resuming button task");
			/* Prevent reading of button press after waking up */
			vTaskDelay(pdMS_TO_TICKS(200));
		}
		deviceManager->check_buttons();
	}
}

/**
 * @brief Task who's sole purpose is to PAUSE / RESUME
 * tasks which get suspended when the inactivity timer
 * expires
 *
 * @param pvParameter
 */
void os_resumer(void *pvParameter)
{
	deviceManager->add_pausable_task(display_task);
	deviceManager->add_pausable_task(button_task);
	deviceManager->start_inactivity_timer();

	/* TODO: Change frequency based on wifi status */
	int pause = 1;
	while (1) {
		ulTaskNotifyTake(pdTRUE, portMAX_DELAY);
		if (pause) {
			ESP_LOGI(MAIN_TAG, "Pausing tasks");
			deviceManager->pause_tasks();
            settings->set_cpu_frequency(INACTIVE_CPU_FREQ_MHZ);
			pause = 0;
		} else {
            settings->set_cpu_frequency(DEFAULT_CPU_FREQ_MHZ);
			deviceManager->resume_inactive_tasks();
			ESP_LOGI(MAIN_TAG, "Resuming tasks");
			deviceManager->reset_inactivity_timer();
			pause = 1;
		}
	}
}

#ifndef UNIT_TEST
extern "C" {
void app_main()
{
	os_init();

	xTaskCreatePinnedToCore(&os_update_display, "os_update_display", 8096, NULL,
							5, &display_task, APP_CPU_NUM);
	xTaskCreatePinnedToCore(&os_gui, "os_gui", 8096, NULL, 6, &gui_task,
							APP_CPU_NUM);
	deviceManager->set_gui_task(gui_task);

	xTaskCreatePinnedToCore(&os_check_buttons, "os_check_buttons", 8096, NULL,
							5, &button_task, APP_CPU_NUM);
	xTaskCreatePinnedToCore(&os_pedometer, "os_pedometer", 8096, NULL, 5, NULL,
							APP_CPU_NUM);
	xTaskCreatePinnedToCore(&os_resumer, "os_resumer", 8096, NULL, 7,
							&resumer_task, APP_CPU_NUM);
}
};
#endif

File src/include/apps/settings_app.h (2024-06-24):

#pragma once
#include "apps/app.h"

#define BUTTON_1 0
#define BUTTON_2 1
#define BUTTON_3 2
#define BUTTON_4 3

class Settings : public App
{
  private:
	lv_obj_t *appMenu;
	lv_obj_t *btnm1;
    lv_obj_t *currentScreen = nullptr;
    lv_obj_t *savedScreen = nullptr;
	int current_button = 0;
	int button_cnt = 4;

    /* Used for displaying the wifi status*/
	lv_obj_t *wifiStatusMenu;
    lv_obj_t *wifiStatusLabel;
    String wifiStatusLabelText;

    lv_obj_t *wifiConfigMenu;
    lv_obj_t *wifiConfigLabel;
    String wifiConfigLabelText;

    lv_obj_t *sntpMenu;
    lv_obj_t *sntpLabel;
    String sntpLabelText;

	static Settings *instance;
	void load_screen() override;
    void load_screen(lv_obj_t *screen);
    void restore_screen(void);
	void button_to_function(int button);
	/**
	 * @brief Callback function associated with pysical
	 * button presses
	 *
	 * @param e
	 */
	static void settings_cb(lv_event_t *e);
    static void button_to_function_task(void *pvParameter);
	void wifi_toggle();
	void wifi_config(void);
    void set_wifi_label_text(const char *text);
    void set_wifi_config_label_text(const char *text);
    void set_sntp_label_text(const char *text);
    void sync_clock();
  public:
	Settings(DeviceManager *deviceManager, String appName)
		: App(deviceManager, appName)
	{
		this->instance = this;
	}
	void setup_ui() override;
	void update_ui() override;
	void handle_button_event(uint32_t event);
};

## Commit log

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2023-11-13 Add schematics and rearange files
    [L96--3DModel-STEP-46669.STEP, licenta.kicad_sch]
2023-11-14 Update schematics w/o PPG
    [licenta.kicad_sch]
2023-11-18 Finish schematic draft
    Add pin headers for PPG and use 1 pin for reading 3 different buttons
    using the ADC. There's not enough space left for the haptic motor
    driver.
    [licenta.kicad_sch]
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2023-11-21 Add ESP32 S3 mini to schematic
    [licenta.kicad_sch]
2023-11-23 board: Modify schematic to use ESP32 S3
    Connect the haptic motor driver to the uC, add labels to pinheaders for A1027
    and connect the buttons to different pins.
    Delete ESP32 C3 mini from schematic.
    [licenta.kicad_sch]
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2023-11-23 board: Add PCB draft
    [licenta.kicad_pcb, licenta.kicad_sch]
2023-11-25 Add fusion sketch
    [SmartCeas v2.f3d]
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2023-12-04 Update schematics
    Delete unused components such as LTR and voltage supervisor.
    Replace pinheaders with test pads
    [licenta.kicad_sch]
2023-12-04 Prototype first PCB version (unrouted)
    [licenta.kicad_pcb, licenta.kicad_sch]
2023-12-08 Add DRU and minor pads update
    [licenta.kicad_pcb, licenta.kicad_sch]
2023-12-11 Add DRC and start routing
    [licenta.kicad_pcb, licenta.kicad_sch]
2023-12-12 Update components layout and route prototype
    Some pins labels on the ESP32 were also modified(BUT NOT THOROUGHLY CHECKED) in order to simplify routing the PCB.
    In addition, this commit also provides some screenshots used for documentation.
    [licenta.kicad_pcb]
2024-02-25 Add STLs for case prototype
    [Smartwatch_case v31_Smartwatch_case v31_Bot.stl, Smartwatch_case v31_Smartwatch_case v31_Button_1.stl, Smartwatch_case v31_Smartwatch_case v31_Top.stl]
2024-03-04 Cleanup repo
    [Smartwatch_case v31_Smartwatch_case v31_Bot.stl, Smartwatch_case v31_Smartwatch_case v31_Button_1.stl, Smartwatch_case v31_Smartwatch_case v31_Top.stl]
2024-03-04 Update PCB design
    This commit changes the button footprints and modifies the silkscreen
    of the PCB.
    [licenta.kicad_pcb, licenta.kicad_sch]
2024-03-04 Modify button alignment
    [licenta.kicad_pcb, licenta.kicad_sch]
2024-03-09 Update PCB and schematics
    This commit replaces the LDO and imports new libraries
    [licenta.kicad_pcb, licenta.kicad_sch]
2024-03-10 Update lib and add 3D models
    [112A-TAAR-R03--3DModel-STEP-56544.STEP, BMI085--3DModel-STEP-56544.STEP, DMG2305UX-7.STEP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]
2024-03-10 Update board and schematic
    This commit adds the following modifications:
    - SDA and SCL pull-ups
    - 100nF debounce capacitors for buttons
    - vias tweaks to not come out of pads
    - connect one button to be used both as BOOT and GPIO
    [licenta.kicad_pcb, licenta.kicad_sch]
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2024-03-13 Update schematic appearance
    [licenta.kicad_sch]
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2024-04-29 Add 3d-files for working prototype
    [Bot layer.step, Button.step, Mid layer.step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]
2024-04-29 refactor: Move components CAD files to a separate directory
    BREAKING CHANGE: Hardcoded Kicad paths will fail for 3D rendering
    [112A-TAAR-R03--3DModel-STEP-56544.STEP, BMI085--3DModel-STEP-56544.STEP, DMG2305UX-7.STEP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]
2024-05-03 Add AceButton libdep
    Library to help with reading events generated by
    the pushdown buttons(long press, short press, double press, etc.)
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2024-05-06 refactor: Settings class no longer inherits App
    [main.cpp]
2024-05-06 feat: Add simple task for processing button events and toggling screen
    Long press SELECT to set BL to OFF
    Double press SELECT to set BL to ON
    Rest of the buttons only print the state and the event in the handler.
2024-05-07 fix: Add missing button pins definitions
    [core.h]
2024-05-07 build: Move PPG sensor deps to local library
    The compiler would complain about some invalid expressions in a source file of the library.
    This commit contains the modified file, simplifying the build process.
2024-05-07 chore: Modify flash partition size
    Closes Modify platformio partition table #15
    [custom_partitions.csv]
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2024-05-13 feat: Modify main for simple components test
    This commit changes `os_init` to only initialize the deviceManager
    (IMU, Display, Buttons and DRV). No WiFi connection is established.
    After initialization, 4 tasks are created:
    - update the Display
    - check button events
    - read accelerometer data and print to serial monitor
    - play first DRV effect
    NOTE: No error checking is done in the event of a miss configuration.
    Check the serial monitor for error logs in that case (the errors
    are not useful for knowing exactly what happened, but they at least
    tell you what failed).
    [main.cpp]
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2024-06-01 feat: Script for logging and visualizing accelerometer data
    This commit also features an incomplete pedometer implementation
    in Python
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2024-06-03 fix: Update deviceManager constructor
    [deviceManager.cpp]
2024-06-03 feat: Pedometer implementation with non-volatile storage step counting
    This commit adds (among other small changes) a task which uses the C-Step-Counter
    library to perform peak detection on accelerometer data.
    This data is also stored on a separate NVS partition on the ESP32S3 every
    10 steps.
    [custom_partitions.csv]
2024-06-05 fix: Configure EN pin of drv2605
    [core.h, drv.cpp]
2024-06-05 test: Add unit tests for SD, DRV, IMU and Display
    To use this you need to run using the pio utilitary.
    No mechanism for separating between normal and test
    build is implemented so you have to comment out app_main
    fro src/main.cpp for this to work.
2024-06-05 feat: Guard app_main in main.cpp during testing
    This commits adds a pre script which inserts the UNIT_TEST define
    before building
2024-06-07 fix: Add missing defines for flash
    [core.h]
2024-06-07 fix: Solve SPI deadlock problem
    [norFlash.cpp]
2024-06-07 feat: Add battery class for displaying battery charge level
    Battery percentage is displayed using a lookup_table which
    linearly maps the adc value to a %
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2024-06-08 feat: Show battery voltage and % on watchface
    Wifi and battery icons placeholders are removed with this commit
2024-06-08 feat: Deep sleep on boot hold and time kept across soft reboots
    This commit moves some initializations from the os_init function
    to the BoardSettings init function.
    With this, the watch attempts to connect to wifi and configure sntp
    only after a hard reboot (RST pressed).
    [core.h, deviceManager.cpp, main.cpp]
2024-06-11 fix: Change incorrect battery test
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2024-06-11 feat: Add script and data for computing voltage to capacity
    [adc_val.csv]
2024-06-12 feat: Add script to configure defines for shared SPI bus with SdFat
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2024-06-22 feat: Settings app placeholder and move through menu
    This commit moves the DEEP_SLEEP function to a separate
    app that can be accessed using DOULBE_PRESS or LONG_PRESS
    on the boot button.
2024-10-18 refactor: Move KiCad board files to a separate dir
    [licenta.kicad_pcb, licenta.kicad_sch]
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2024-10-18 feat: Update 3D files
    [Bot layer.step, Button.step, Mid layer.step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]
